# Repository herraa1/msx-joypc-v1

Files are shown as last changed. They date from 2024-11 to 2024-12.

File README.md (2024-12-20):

# PC gameport joystick controller adapter for MSX (msx-joypc) v1

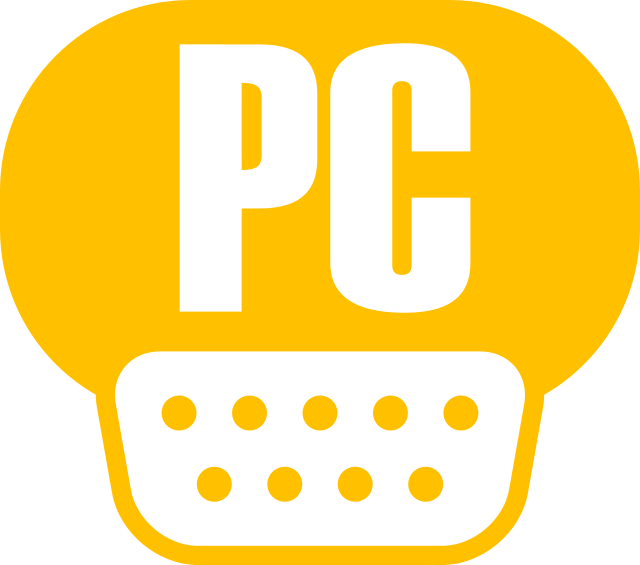
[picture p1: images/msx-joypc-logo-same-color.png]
[](images/msx-joypc-logo-same-color.png)

Connect [PC gameport joysticks](https://en.wikipedia.org/wiki/Game_port) to [MSX computers](https://www.msx.org/wiki/).

> [!NOTE]
>
> No build instructions are yet provided, but if you are brave enough go for the [recommended build](#recommended-build).
>

## Introduction

The msx-joypc v1 is an adapter that allows connecting PC gameport joysticks to [MSX general purpose I/O ports](https://www.msx.org/wiki/General_Purpose_port).

The main features of the msx-joypc v1 adapter are:
* small footprint
* made of widely available electronic components
* behaves as a cord extension between the MSX computer and the PC gameport joystick
* uses a female standard DE9 connector on the adapter's MSX joystick side
* uses a [DA-15](https://en.wikipedia.org/wiki/D-subminiature) socket on the adapter's PC gameport joystick side
* no need for external power supply, the adapter draws current from the MSX port
* low power consumption (<20mA)
* serial debug provides information about the operation of the adapter

## [Hardware](hardware/kicad/)

The msx-joypc v1 adapter uses an [Atmega328p](https://en.wikipedia.org/wiki/ATmega328) to convert the [PC gameport joystick signalling](https://www.epanorama.net/documents/joystick/pc_joystick.html) to the [MSX joystick standard signalling](https://www.msx.org/wiki/Joystick_control).

A two-sided printed circuit board (PCB) is used to put together all components:
* An Atmega328p as the main MCU, running at 5V 16MHz
* Two 74LS03 quad 2-input NAND gates with open collectors to completely mimic the standard MSX joystick behavior
* A PTC fuse to minimize damage to the MSX computer in case something goes wrong with the board
* Several additional required components (crystal, diode, leds, resistors, ceramic capacitors and a tantalum capacitor)
* An angled DA-15 socket is used to directly connect the PC gameport joystick
* A PH2.0 connector is used to connect the MSX cable extension
* A 2.54 pitch debug header is added for serial debug and programming
* An ICSP header is provided for burning a bootloader or to flash the chip using a hardware programmer
* A DIP switch to configure the adapter for compatibility with different PC joysticks

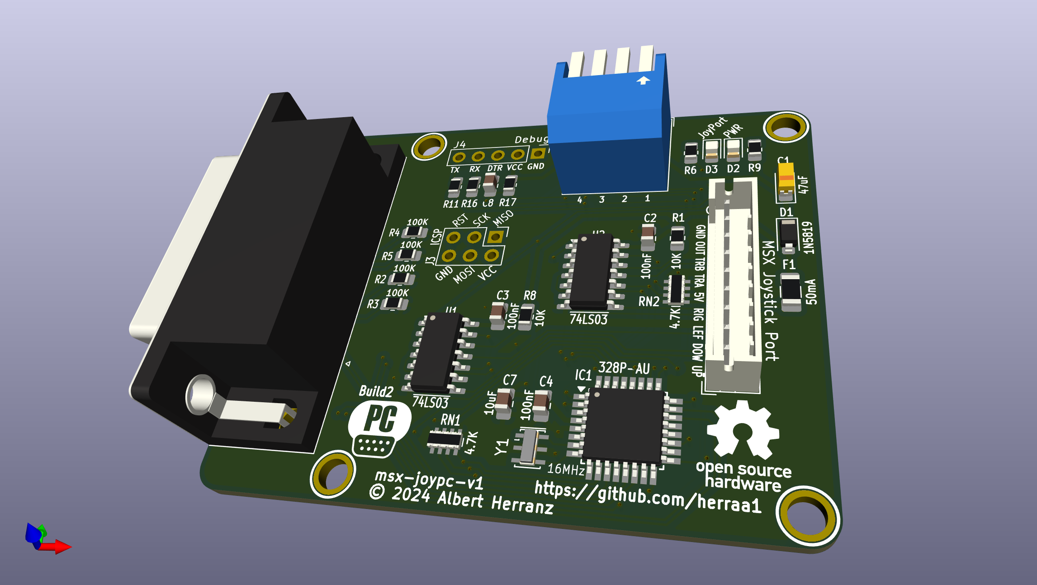
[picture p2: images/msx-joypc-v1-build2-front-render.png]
[](images/msx-joypc-v1-build2-front-render.png)
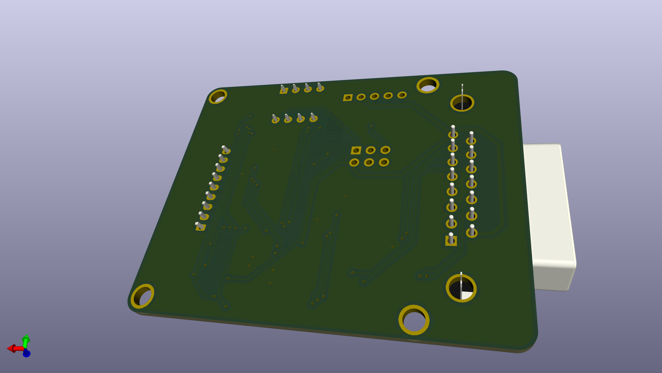
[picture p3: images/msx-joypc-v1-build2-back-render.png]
[](images/msx-joypc-v1-build2-back-render.png)

Connection to the MSX general purpose I/O port is implemented using a DE9 joystick extension cable with a female DE9 connector on one side and a loose end on the other side.
The MSX joystick extension cable loose end is wired according to the following pinout mapping.

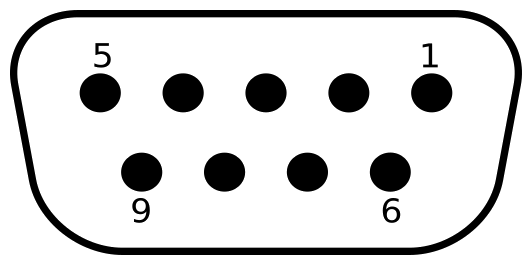
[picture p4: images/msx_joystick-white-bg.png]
| [](images/msx_joystick-white-bg.png) |
|:--|
| MSX joystick connector pinout, from controller plug side |

| MSX side pin | Cable color (may vary) | Signal |
| --- | --- | --- |
| 5 | Brown | +5v |
| 4 | Orange | RIGHT  |
| 3 | Grey | LEFT |
| 2 | Black | DOWN |
| 1 | Red | UP |
| 6 | Green | TRIGA  |
| 7 | White | TRIGB  |
| 8 | Blue | OUT |
| 9 | Yellow | GND |

The msx-joypc v1 is fully compatible with MSX joysticks and honors the pin8 (OUT) signal.

The adapter uses open collector outputs (using 74LS03 Quad 2-Input NAND gates with open collector outputs) which makes the adapter safer [^2] than the
standard MSX joystick schematic depicted in the MSX Technical Data Book, as it avoids a series of undesired conditions that can lead to bus contention/short circuits.

Power is drawn from the +5V signal of the MSX general purpose I/O port, which is capable of delivering up to 50mA [^1].
The msx-joypc v1 draws below 20mA from the port when a controller is connected, so it is on the safe side. Anyway, the msx-joypc adapter uses a Positive Temperature Coeficient (PTC) resettable fuse of 50mA (F1) to limit current in case something goes wrong.

Also on the power side, a [1N5819 Schottky diode](https://www.diodes.com/assets/Datasheets/1N5819HW.pdf) (D1) is used to avoid leaking current from the msx-joypc adapter to the MSX in case power is applied to one of the VCC pins available on the ICSP or Debug headers while the adapter is plugged into an MSX.

Connection to the PC gameport joystick is done via a PC gameport joystick socket.

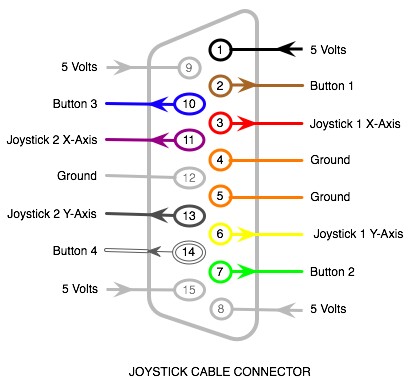
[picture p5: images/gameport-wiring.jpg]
| [](images/gameport-wiring.jpg) |
|:--|
| Gameport connector pinout, from PC gameport joystick side |

| Gameport pin | Signal | Comment |
| --- | ---| --- |
| 1 | +5V | +5V power |
| 2 | B1 | Button1 |
| 3 | X1 | Joystick 1 - X axis |
| 4 | GND | ground |
| 5 | GND | ground |
| 6 | Y1 | Joystick 1 - Y axis |
| 7 | B2 | Button2 |
| 8 | +5V | +5V power |
| 9 | +5V | +5V power |
| 10 | B3 | Button3 |
| 11 | X2 | Joystick 2 - X axis |
| 12 | GND/MIDI_OUT | ground / MIDI out |
| 13 | Y2 | Joystick 2 - Y axis |
| 14 | B4 | Button4 |
| 15 | +5V/MIDI_IN  | +5V power / MIDI_IN |

The PC gameport joystick uses 5V for power and logic.

Power for the PC gameport joystick is provided by the MSX +5V rail.

### Recommended Build

Please, use [msx-joypc-v1 Build2](#build2) for making new boards.

### [Build2](hardware/kicad/msx-joypc-v1-build2)

[Bill Of Materials (BoM)](https://html-preview.github.io/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)

This build fixes the following errata:
- make the ICSP header work again
- add (optional) RN1 and RN2 4k7 pull-downs to joystick signals to avoid spurious button joystick actions while powering up

This board has been successfully built and works fine.

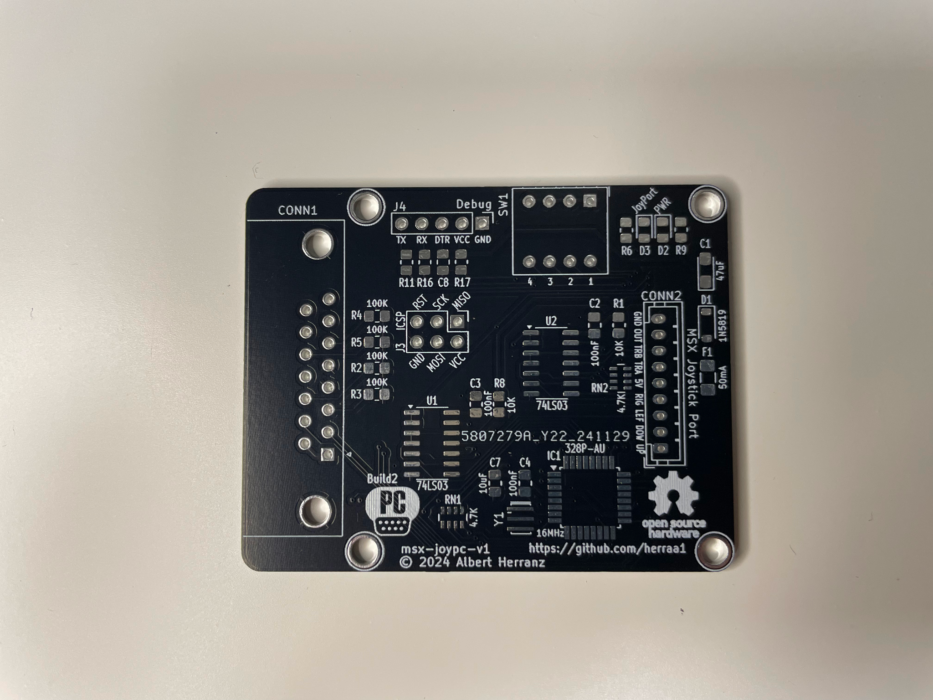
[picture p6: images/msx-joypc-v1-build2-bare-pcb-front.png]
[](images/msx-joypc-v1-build2-bare-pcb-front.png)
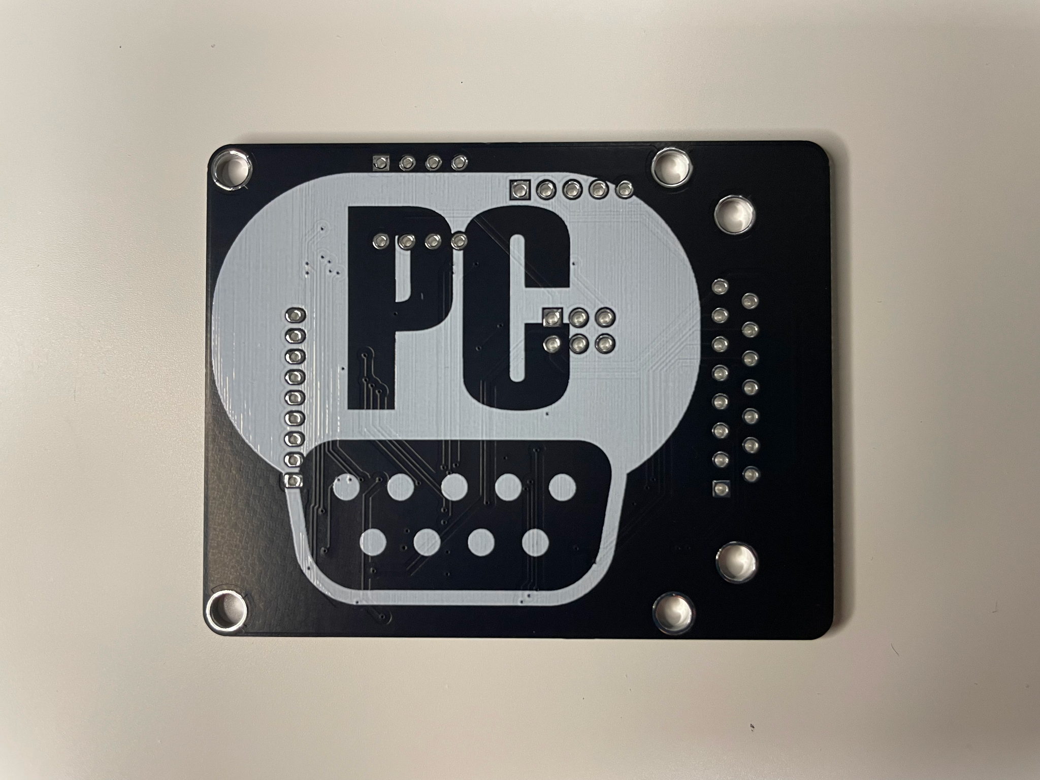
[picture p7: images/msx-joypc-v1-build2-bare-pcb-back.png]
[](images/msx-joypc-v1-build2-bare-pcb-back.png)

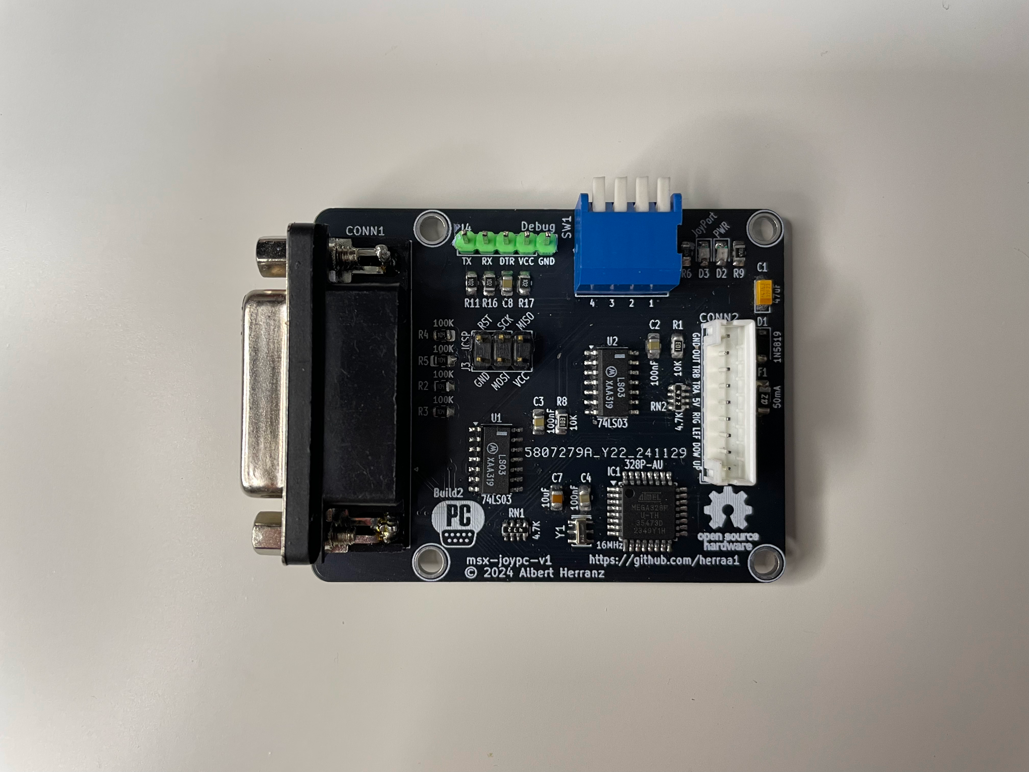
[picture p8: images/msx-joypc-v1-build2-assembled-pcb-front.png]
[](images/msx-joypc-v1-build2-assembled-pcb-front.png)
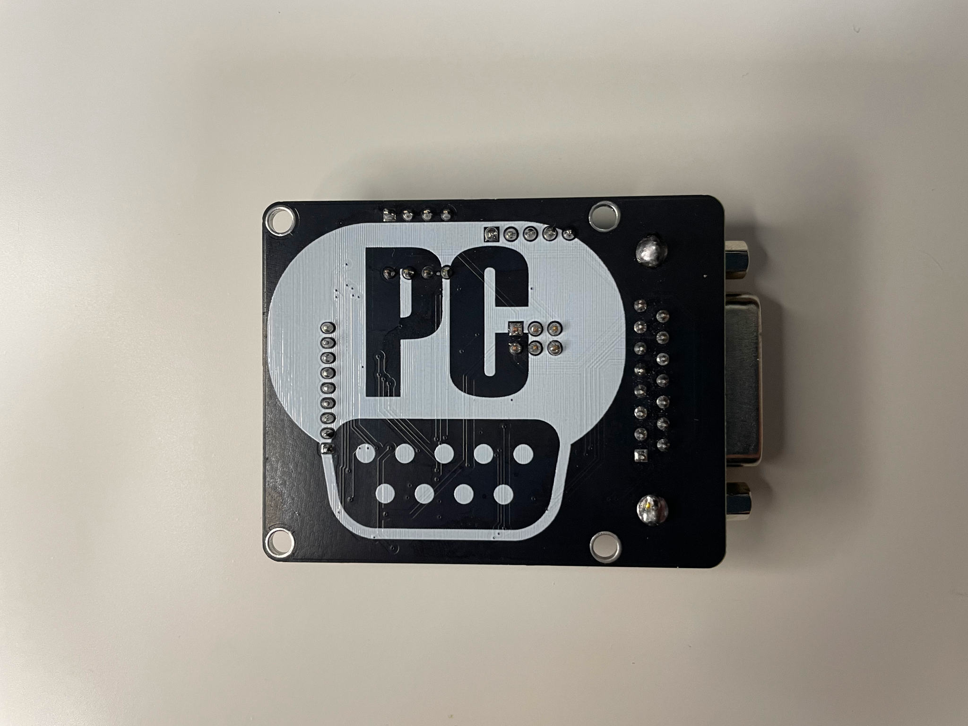
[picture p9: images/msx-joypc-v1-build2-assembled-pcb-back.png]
[](images/msx-joypc-v1-build2-assembled-pcb-back.png)

### Build1

> [!WARNING]
> This build is broken. I messed up the ICSP header after a last-minute pin reordering. Meh.
> It can be fixed by cutting two traces, exposing two traces and using a pair of jumper wires to bridge the necessary points.
>
> Do NOT build. Use the [recommended build](#recommended-build) instead.
>

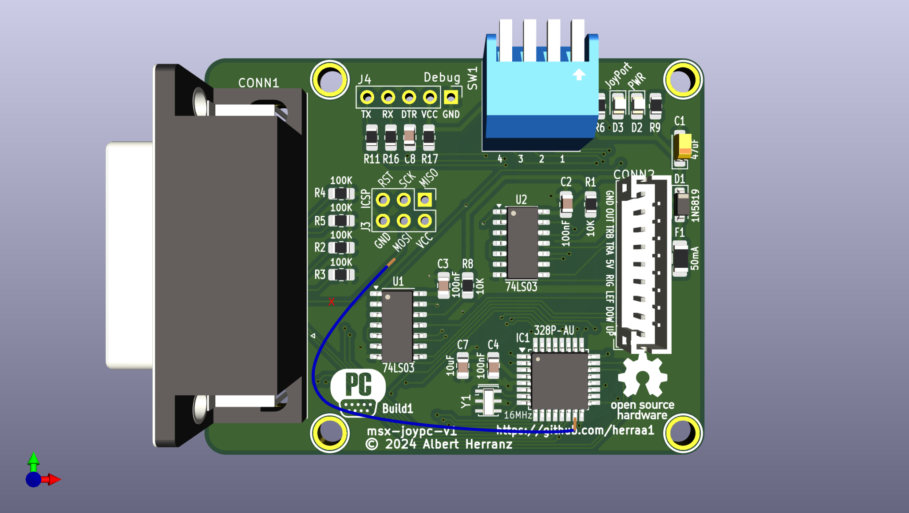
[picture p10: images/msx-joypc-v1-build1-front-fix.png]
[](images/msx-joypc-v1-build1-front-fix.png)
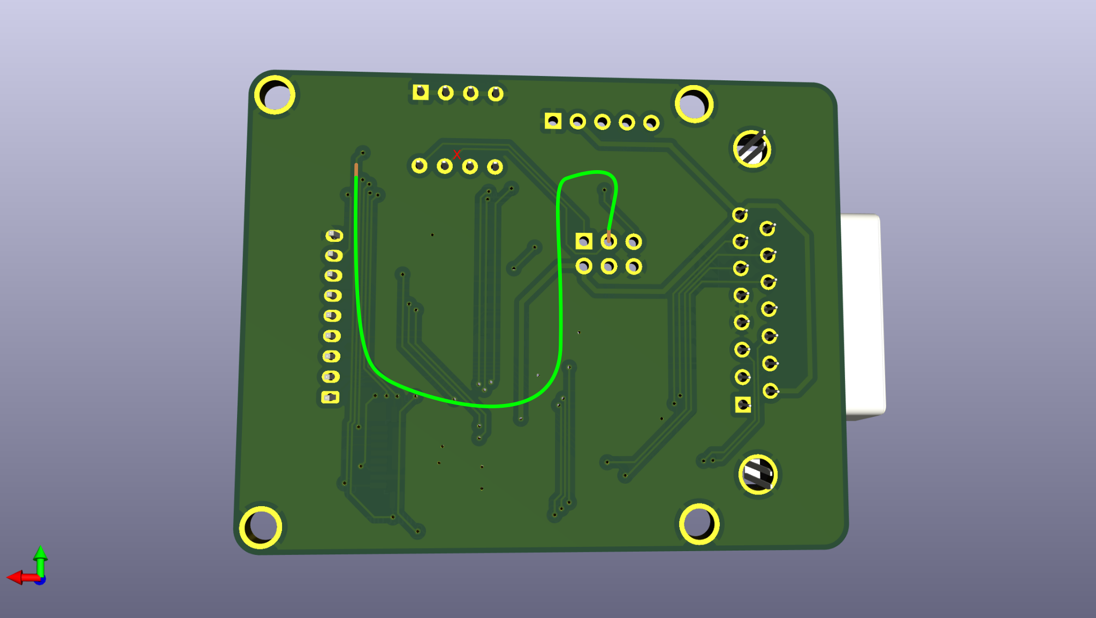
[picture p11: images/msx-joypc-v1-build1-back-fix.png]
[](images/msx-joypc-v1-build1-back-fix.png)

## [Firmware](firmware/msx-joypc-v1/)

The msx-joypc v1 adapter firmware uses a slightly modified version of [Necroware's GamePort adapter firmware](https://github.com/necroware/gameport-adapter) to read the PC gameport joystick status.

The following elements are used as inputs:
* joystick X and Y axis as direction arrows
* button 1, as Trigger 1
* button 2, as Trigger 2

Those elements' status are processed by the msx-joypc firmware and transformed into MSX general purpose I/O port's signals on the fly.

## [Enclosure](enclosure/)

### Acrylic

A simple acrylic enclosure design for the project is provided to protect the electronic components and provide strain relief for the extension cord.

The enclosure uses a 3mm acrylic sheet.

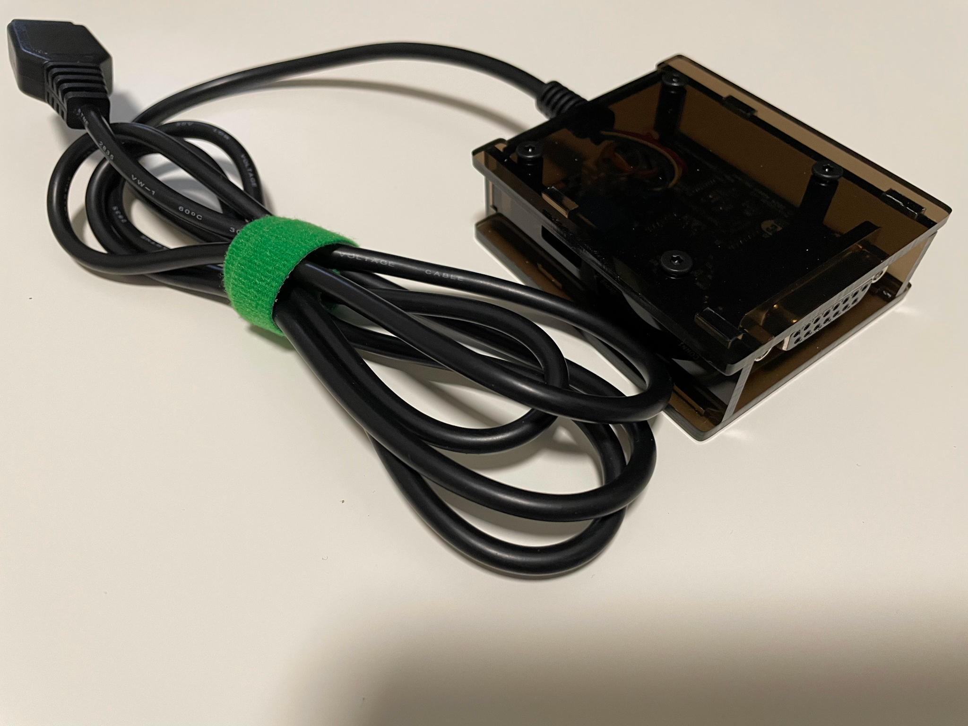
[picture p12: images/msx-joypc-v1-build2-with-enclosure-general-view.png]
[](images/msx-joypc-v1-build2-with-enclosure-general-view.png)

## Configuration Switches

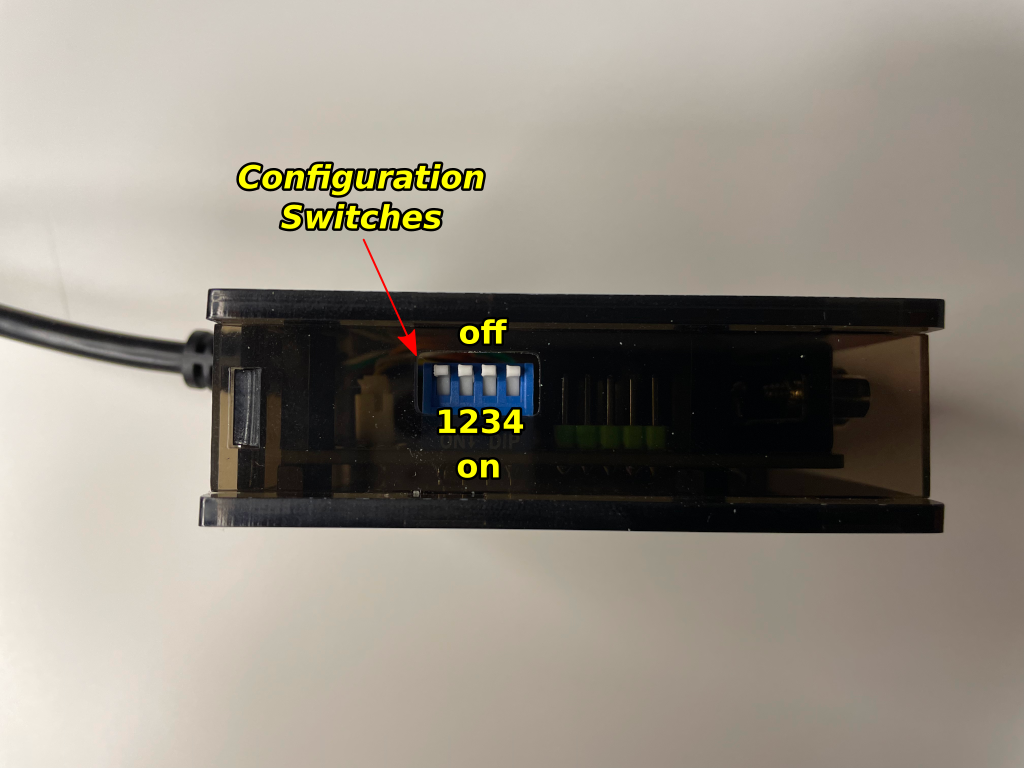
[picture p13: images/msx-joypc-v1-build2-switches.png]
[](images/msx-joypc-v1-build2-switches.png)

Joystick Model               | Buttons | Axes  |  Hat | SW1-4 | Protocol   | Comments
-----------------------------|---------|-------|------|-------|------------|------------------------------------
Generic Analog               | 2       | 2     | 0    | 0000  | Analogue   |
Generic Analog               | 4       | 2     | 0    | 1000  | Analogue   |
Generic Analog               | 4       | 3     | 0    | 0100  | Analogue   | 3rd Axis is throttle
Generic Analog               | 4       | 4     | 0    | 1100  | Analogue   |
CH FlightStick               | 4       | 4     | 1    | 0010  | Analogue   |
CH F16 Combat Stick          | 10      | 3     | 1    | 0110  | Analogue   |
ThrustMaster                 | 4       | 3     | 1    | 1010  | Analogue   |
Sidewinder GamePad           | 10      | 2     | 0    | 1110  | Sidewinder |
Sidewinder 3D Pro            | 8       | 4     | 1    | 1110  | Sidewinder |
Sidewinder 3D Pro Plus       | 9       | 4     | 1    | 1110  | Sidewinder | First version of Precision Pro
Sidewinder Precision Pro     | 9       | 4     | 1    | 1110  | Sidewinder |
Sidewinder FFB Pro           | 9       | 4     | 1    | 1110  | Sidewinder | FFB not yet implemented
Sidewinder FFB Wheel         | 8       | 3     | 0    | 1110  | Sidewinder | FFB not yet implemented
Gravis GamePad Pro           | 10      | 2     | 0    | 0001  | GrIP       |
Logitech WingMan Extreme     | 6       | 3     | 1    | 1001  | ADI        |
Logitech CyberMan 2          | 8       | 6     | 0    | 1001  | ADI        |
Logitech WingMan Interceptor | 9       | 3     | 3    | 1001  | ADI        | 2 hats are mapped as 4 axes
Logitech ThunderPad Digital  | 8       | 2     | 0    | 1001  | ADI        | Directional buttons mapped as 2 axes
Logitech WingMan Gamepad     | 11      | 2     | 0    | 1001  | ADI        | Directional buttons mapped as 2 axes
Logitech WingMan Light       | 2       | 2     | 0    | 0000  | Analogue   |

For an up to date information see [Which joysticks does this adapter support](https://github.com/necroware/gameport-adapter?tab=readme-ov-file#which-joysticks-does-this-adapter-support) on [Necroware's GamePort adapter project](https://github.com/necroware/gameport-adapter).

## LED indicators

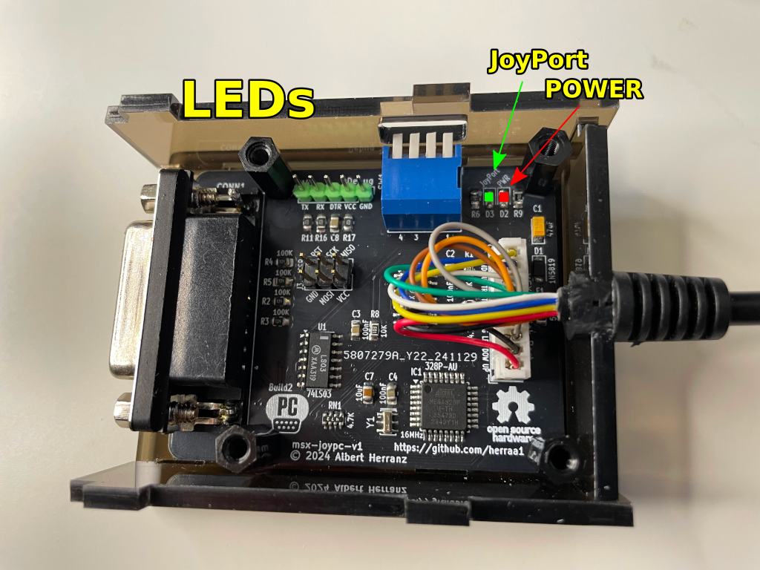
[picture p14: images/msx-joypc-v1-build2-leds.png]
[](images/msx-joypc-v1-build2-leds.png)

| **LED** | **State** | **Indication** |
|---|---|---|
| _POWER_ | Off | board is not receiving 5V power |
| _POWER_ | Solid Red | board is receiving 5V power |
| _JoyPort_ | Off | no PC joystick connected or recognized |
| _JoyPort_ | Solid Green | PC joystick connected and ready to use |

## References

MSX general purpose I/O port
* https://www.msx.org/wiki/General_Purpose_port

Atmega328p pinout
- https://camo.githubusercontent.com/06bc0a6bb71729956af107f56c3e57bd065d9fb924bcc7f6bb8fbb487a1a5e55/68747470733a2f2f692e696d6775722e636f6d2f6e6177657145362e6a7067

Joystick PC Gameport pinout
* https://allpinouts.org/pinouts/connectors/input_device/joystick-pc-gameport/

PC joystick interface
* https://www.epanorama.net/documents/joystick/pc_joystick.html

Necroware's GamePort adapter project
* https://github.com/necroware/gameport-adapter

Using a PC Joystick with the Arduino
* http://www.built-to-spec.com/blog/2009/09/10/using-a-pc-joystick-with-the-arduino/

Arduino gameport interface
* https://build-its.blogspot.com/2012/01/arduino-game-port-interface.html

DIY gameport to USB adapter
* https://littlebigtech.net/posts/diy-gameport-to-usb-adapter/

## Image Sources

* https://www.oshwa.org/open-source-hardware-logo/
* https://en.wikipedia.org/wiki/File:Numbered_DE9_Diagram.svg

[^1]: https://www.msx.org/wiki/General_Purpose_port
[^2]: https://www.msx.org/wiki/Joystick/joypad_controller (see "Undesired Conditions")

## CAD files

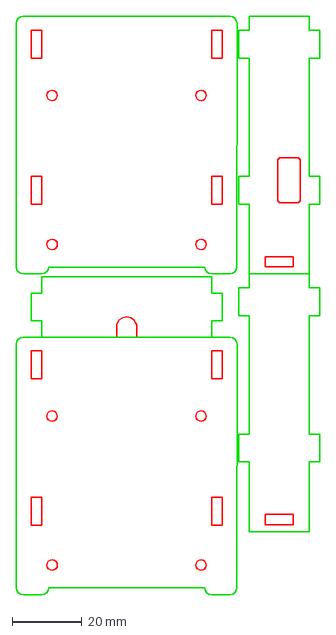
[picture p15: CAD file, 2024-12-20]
enclosure/msx-joypc-v1-case-acrylic-3mm-ready-to-lasercut.dxf
87.1 x 166.1 mm

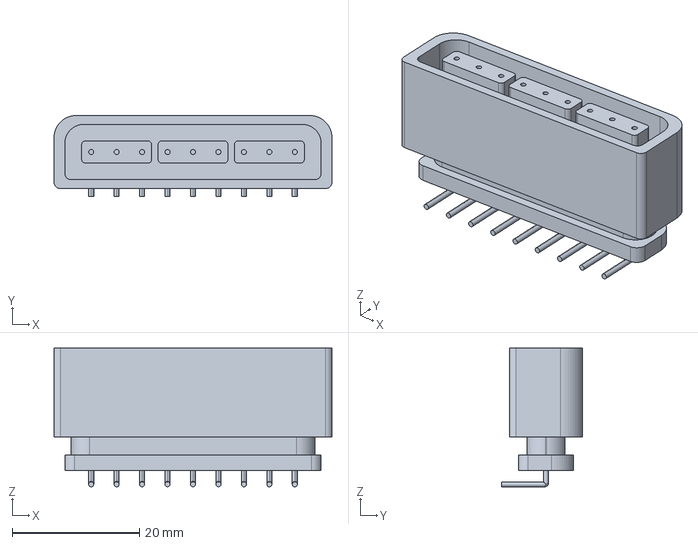
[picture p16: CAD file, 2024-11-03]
hardware/kicad/msx-joypc-v1-build2/compo/3dmodels/ps-connector-female/pritesh.stp
43.7 x 12.8 x 21.8 mm

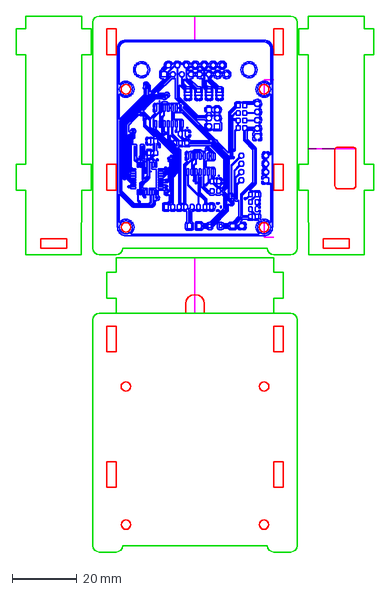
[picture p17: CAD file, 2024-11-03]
enclosure/msx-joypc-v1-case.dxf
110.9 x 166.1 mm

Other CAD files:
hardware/kicad/msx-joypc-v1-build2/compo/3dmodels/ps-connector-female/pritesh.igs

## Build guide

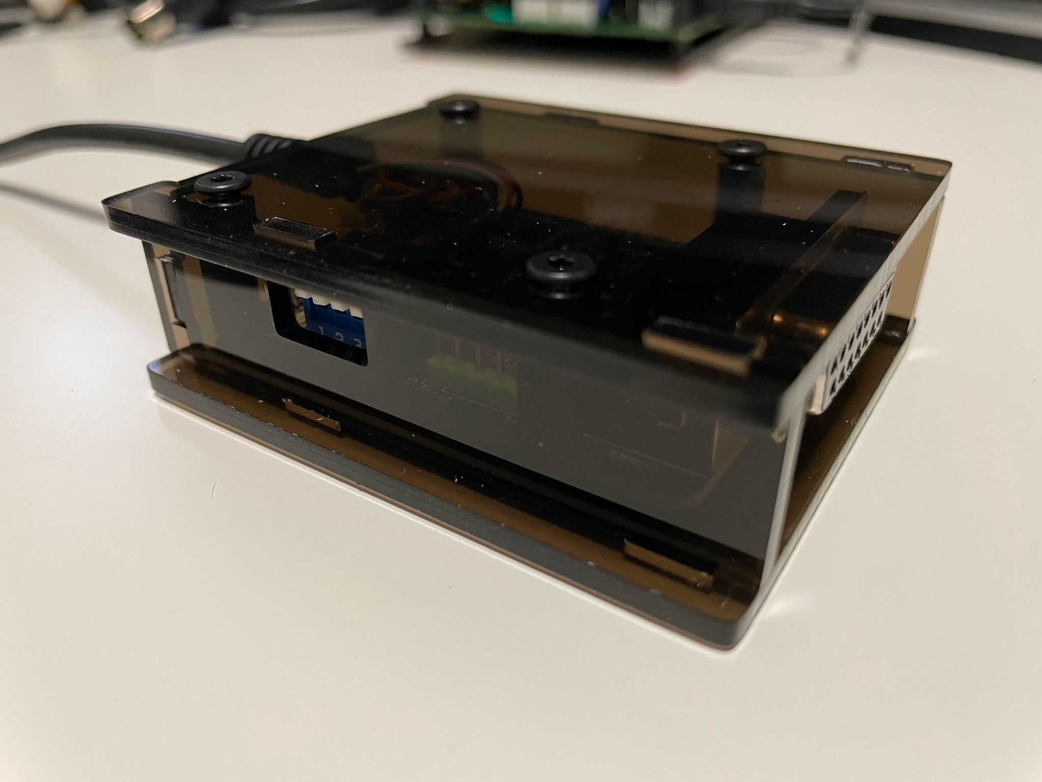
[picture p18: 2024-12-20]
images/msx-joypc-v1-build2-with-enclosure-view-of-switches.png

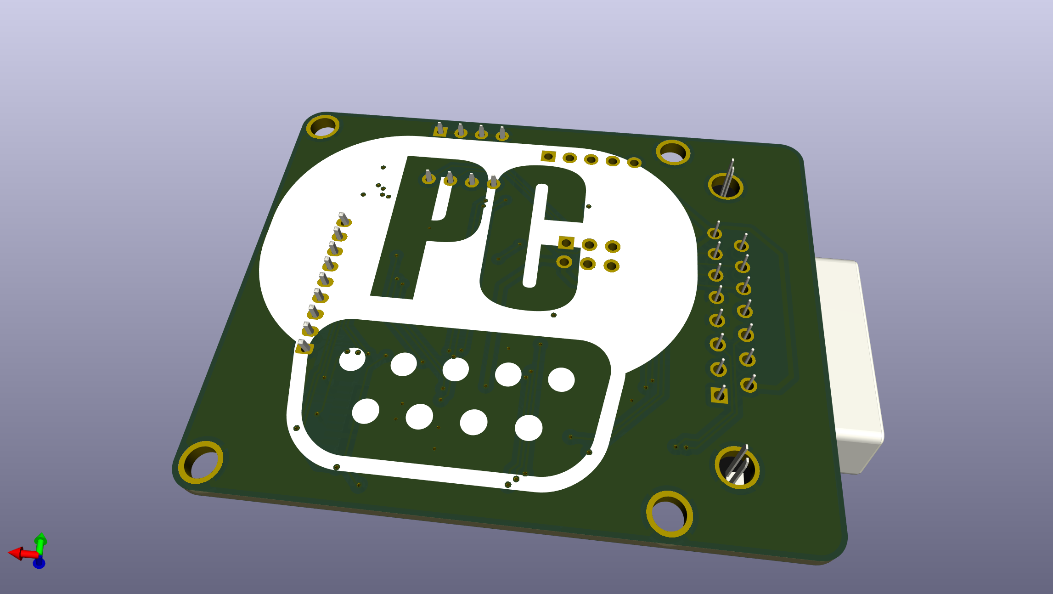
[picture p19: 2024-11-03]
images/msx-joypc-v1-build1-back-render.png

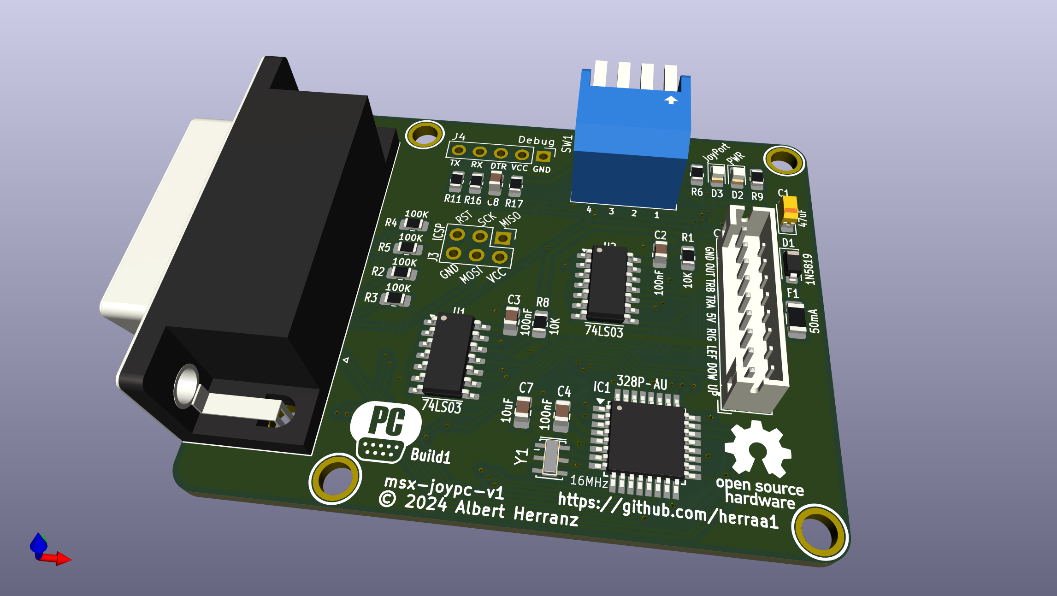
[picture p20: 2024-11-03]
images/msx-joypc-v1-build1-front-render.png

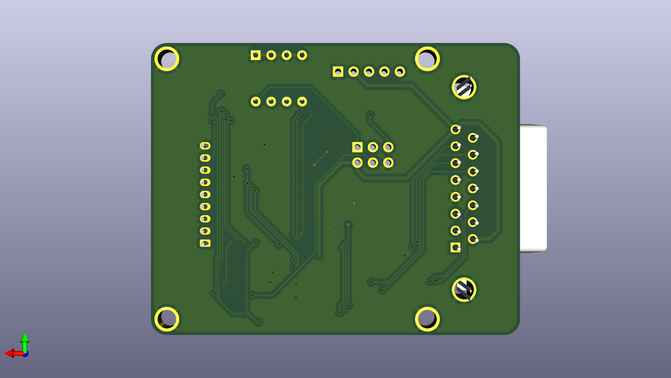
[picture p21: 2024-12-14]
images/msx-joypc-v1-build2-back.png

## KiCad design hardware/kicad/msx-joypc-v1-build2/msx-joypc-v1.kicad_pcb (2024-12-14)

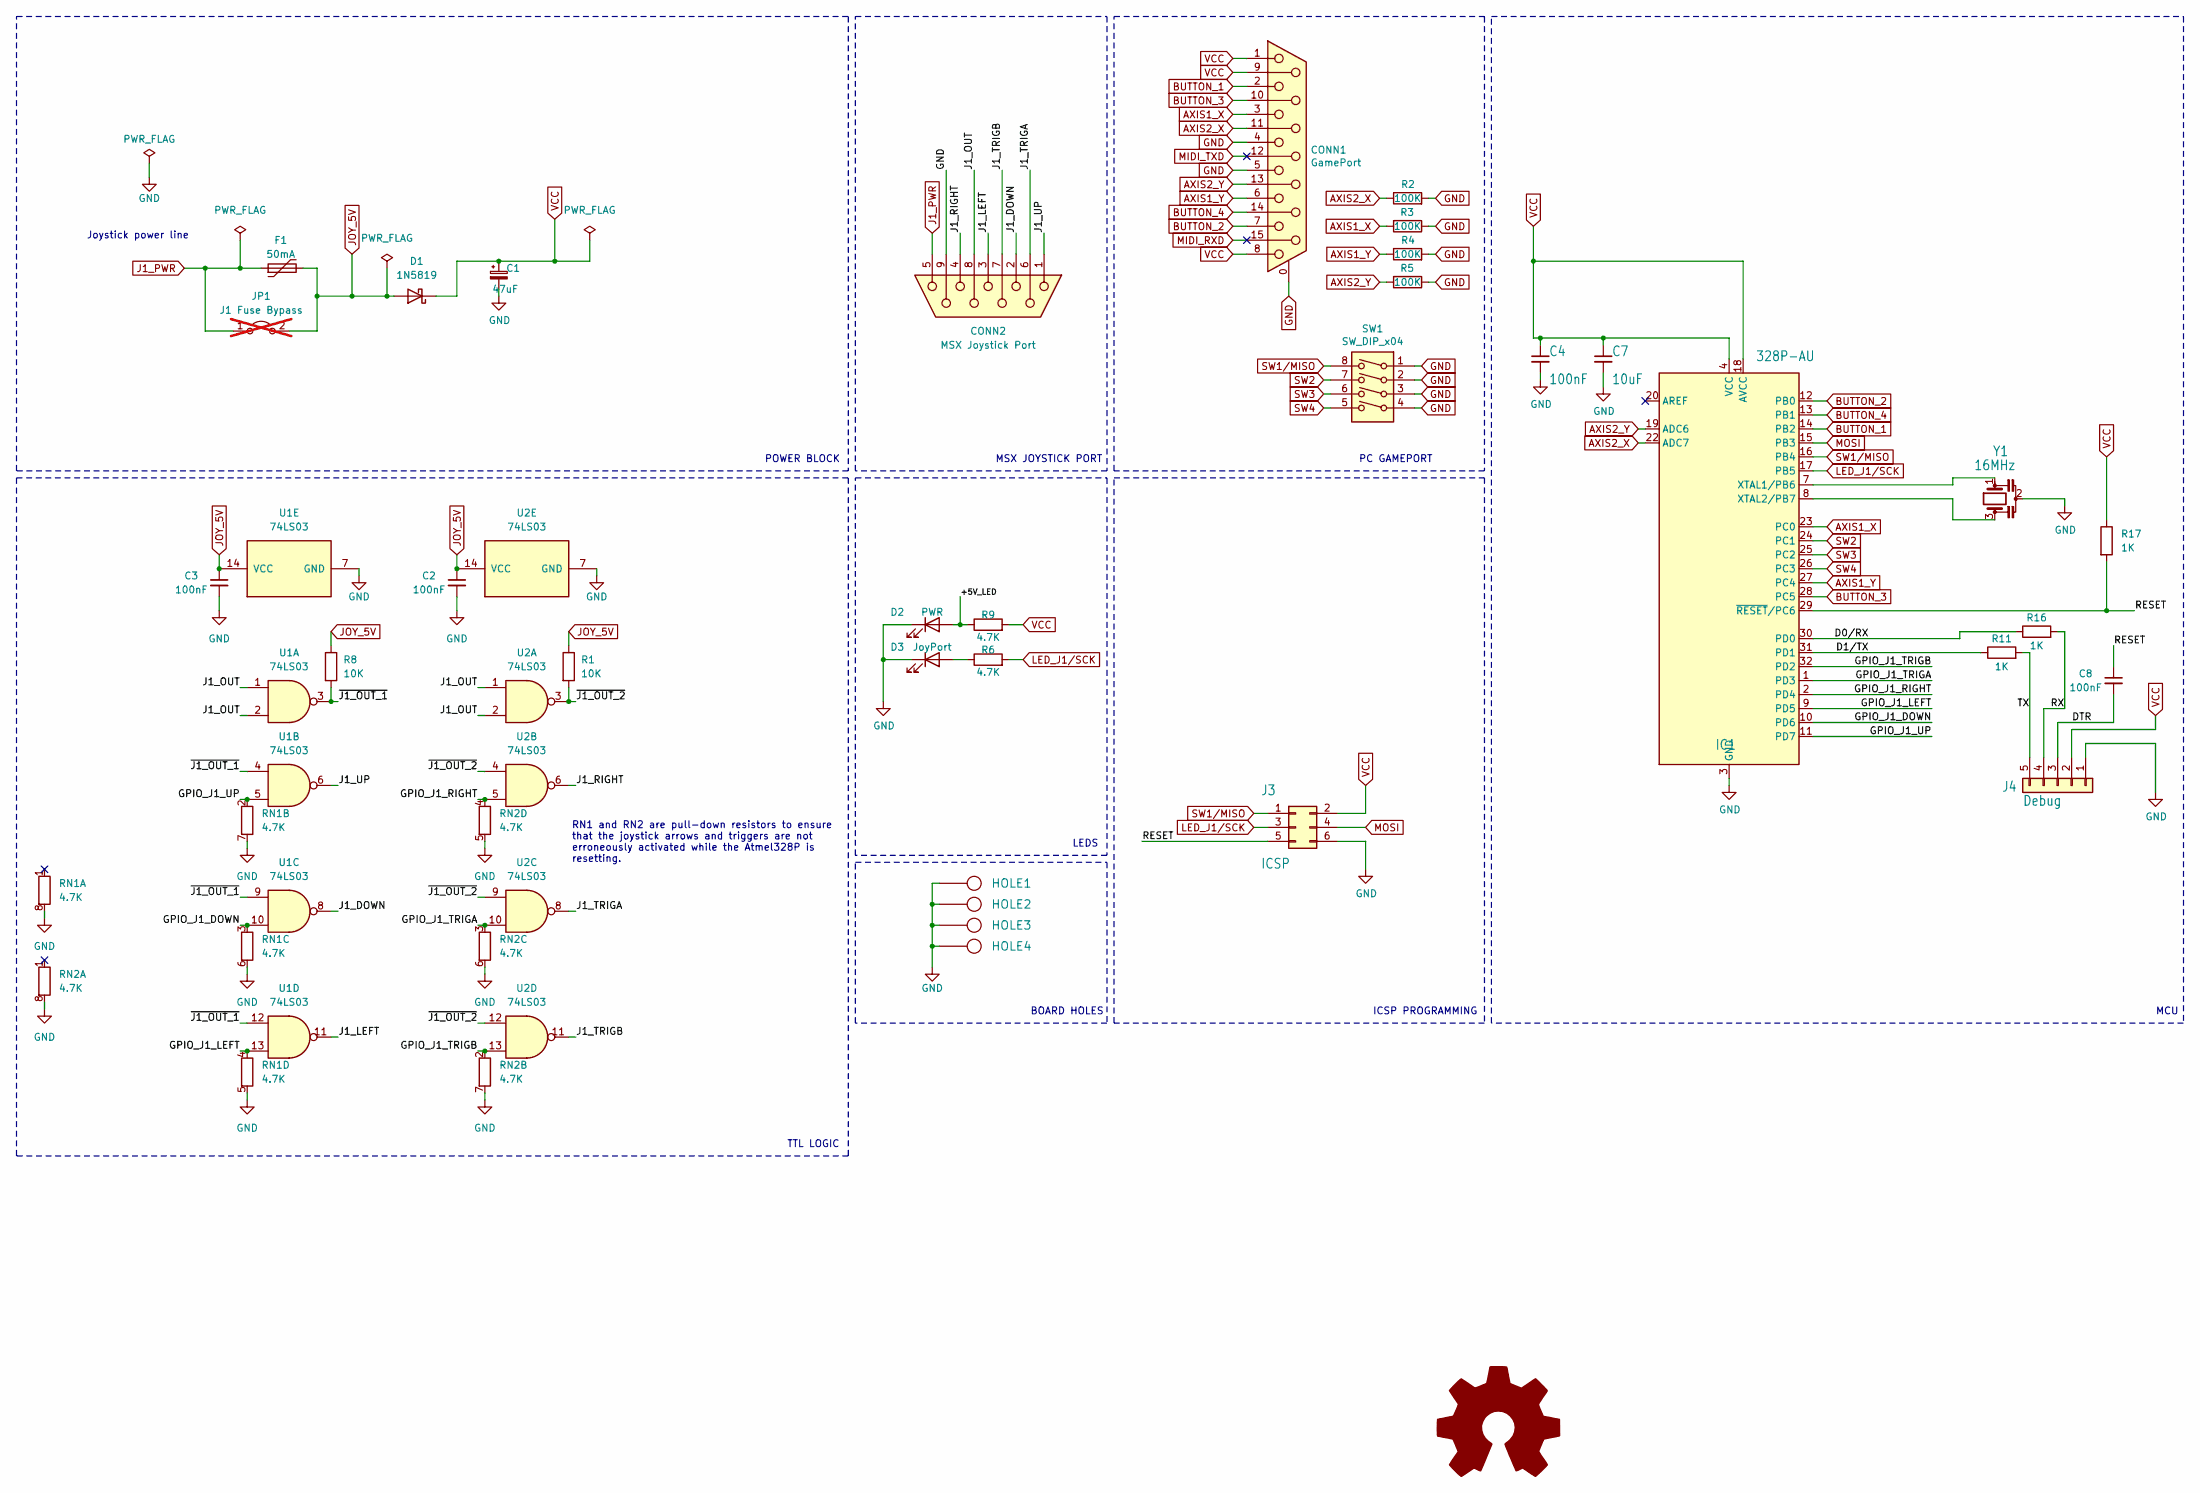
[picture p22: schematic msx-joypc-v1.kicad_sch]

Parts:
C1: 47uF; CP_EIA-3216-18_Kemet-A_Pad1.58x1.35mm_HandSolder
C2, C3, C4, C8: 100nF; C_0805_2012Metric_Pad1.18x1.45mm_HandSolder
C7: 10uF; C_0805_2012Metric_Pad1.18x1.45mm_HandSolder
CONN1: GamePort; DSUB-15_Female_Horizontal_P2.77x2.84mm_EdgePinOffset7.70mm_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; LCSC C77835
CONN2: MSX Joystick Port; JST_PH_B9B-PH-K_1x09_P2.00mm_Vertical
D1: 1N5819; D_SOD-123
D2: PWR; LED_0805_2012Metric_Pad1.15x1.40mm_HandSolder
D3: JoyPort; LED_0805_2012Metric_Pad1.15x1.40mm_HandSolder
F1: 50mA; Fuse_1206_3216Metric_Pad1.42x1.75mm_HandSolder
HOLE1, HOLE2, HOLE3, HOLE4: HOLE; Hole_3mm
IC1: 328P-AU; TQFP-32_7x7mm_P0.8mm
J3: ICSP; PinHeader_2x03_P2.54mm_Vertical
J4: Debug; PinHeader_1x05_P2.54mm_Vertical
JP1: J1 Fuse Bypass; PinHeader_1x02_P2.54mm_Vertical; not fitted
R1, R8: 10K; R_0805_2012Metric_Pad1.20x1.40mm_HandSolder
R2, R3, R4, R5: 100K; R_0805_2012Metric_Pad1.20x1.40mm_HandSolder; LCSC C172965
R6: 4.7K; R_0805_2012Metric_Pad1.20x1.40mm_HandSolder; LCSC C4310
R9: 4.7K; R_0805_2012Metric_Pad1.20x1.40mm_HandSolder
R11, R16, R17: 1K; R_0805_2012Metric_Pad1.20x1.40mm_HandSolder
RN1, RN2: 4.7K; R_Array_Concave_4x0603
SW1: SW_DIP_x04; SW_DIP_SPSTx04_Piano_10.8x11.72mm_W7.62mm_P2.54mm; LCSC C15781
SYM1: Logo_Open_Hardware_Large; OSHW-Logo_7.5x8mm_SilkScreen
U1, U2: 74LS03; SOIC-14_3.9x8.7mm_P1.27mm
Y1: 16MHz; Resonator_SMD_Murata_CSTxExxV-3Pin_3.0x1.1mm_HandSoldering

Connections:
/+5V_LED: D2.2 (A), R9.1
/D0/RX: IC1.30 (PD0), R16.1
/D1/TX: IC1.31 (PD1), R11.1
/DTR: C8.2, J4.3
/GPIO_J1_DOWN: IC1.10 (PD6), RN1.3 (R3.1), U1.10
/GPIO_J1_LEFT: IC1.9 (PD5), RN1.4 (R4.1), U1.13
/GPIO_J1_RIGHT: IC1.2 (PD4), RN2.4 (R4.1), U2.5
/GPIO_J1_TRIGA: IC1.1 (PD3), RN2.3 (R3.1), U2.10
/GPIO_J1_TRIGB: IC1.32 (PD2), RN2.2 (R2.1), U2.13
/GPIO_J1_UP: IC1.11 (PD7), RN1.2 (R2.1), U1.5
/J1_DOWN: CONN2.2, U1.8
/J1_LEFT: CONN2.3, U1.11
/J1_OUT: CONN2.8, U1.1, U1.2, U2.1, U2.2
/J1_RIGHT: CONN2.4, U2.6
/J1_TRIGA: CONN2.6, U2.8
/J1_TRIGB: CONN2.7, U2.11
/J1_UP: CONN2.1, U1.6
/RESET: C8.1, IC1.29 (~RESET/PC6), J3.5, R17.2
/RX: J4.4, R16.2
/TX: J4.5, R11.2
/~J1_OUT_1: R8.2, U1.3, U1.4, U1.9, U1.12
/~J1_OUT_2: R1.2, U2.3, U2.4, U2.9, U2.12
AXIS1_X: CONN1.3, IC1.23 (PC0), R3.2
AXIS1_Y: CONN1.6, IC1.27 (PC4), R4.1
AXIS2_X: CONN1.11 (P111), IC1.22 (ADC7), R2.1
AXIS2_Y: CONN1.13, IC1.19 (ADC6), R5.2
BUTTON_1: CONN1.2, IC1.14 (PB2)
BUTTON_2: CONN1.7, IC1.12 (PB0)
BUTTON_3: CONN1.10, IC1.28 (PC5)
BUTTON_4: CONN1.14, IC1.13 (PB1)
GND: C1.2, C2.2, C3.2, C4.2, C7.2, CONN1.0 (PAD), CONN1.4, CONN1.5, CONN2.9, D2.1 (K), D3.1 (K), HOLE1.1, HOLE2.1, HOLE3.1, HOLE4.1, IC1.3 (GND), IC1.5 (GND), IC1.21 (GND), J3.6, J4.1, R2.2, R3.1, R4.2, R5.1, RN1.5 (R4.2), RN1.6 (R3.2), RN1.7 (R2.2), RN1.8 (R1.2), RN2.5 (R4.2), RN2.6 (R3.2), RN2.7 (R2.2), RN2.8 (R1.2), SW1.1, SW1.2, SW1.3, SW1.4, U1.7 (GND), U2.7 (GND), Y1.2
J1_PWR: CONN2.5, F1.1, JP1.1 (A)
JOY_5V: C2.1, C3.1, D1.2 (A), F1.2, JP1.2 (B), R1.1, R8.1, U1.14 (VCC), U2.14 (VCC)
LED_J1/SCK: IC1.17 (PB5), J3.3, R6.2
MIDI_RXD: CONN1.15
MIDI_TXD: CONN1.12
MOSI: IC1.15 (PB3), J3.4
unnamed: D3.2 (A), R6.1
unnamed: IC1.7 (XTAL1/PB6), Y1.1
unnamed: IC1.8 (XTAL2/PB7), Y1.3
SW1/MISO: IC1.16 (PB4), J3.1, SW1.8
SW2: IC1.24 (PC1), SW1.7
SW3: IC1.25 (PC2), SW1.6
SW4: IC1.26 (PC3), SW1.5
VCC: C1.1, C4.1, C7.1, CONN1.1, CONN1.8, CONN1.9, D1.1 (K), IC1.4 (VCC), IC1.6 (VCC), IC1.18 (AVCC), J3.2, J4.2, R9.2, R17.1

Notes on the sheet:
MCU
LEDS
MSX JOYSTICK PORT
TTL LOGIC
BOARD HOLES
Joystick power line
ICSP PROGRAMMING
RN1 and RN2 are pull-down resistors to ensure that the joystick arrows and triggers are not erroneously activated while the Atmel328P is resetting.
PC GAMEPORT
POWER BLOCK

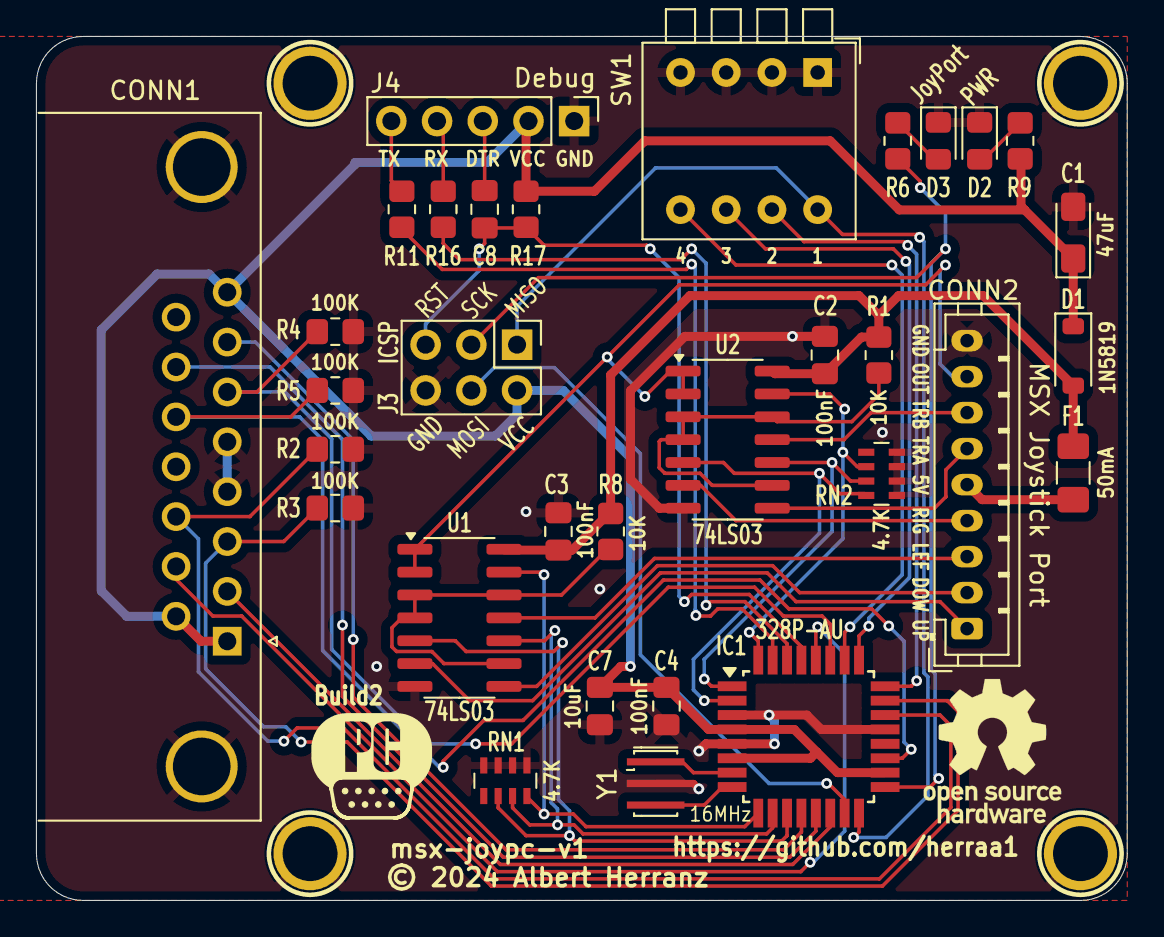
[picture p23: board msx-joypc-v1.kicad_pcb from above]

Board: 2 copper layers, 60.6 x 48.0 mm, 37 parts (0 on the bottom side), 43 nets.

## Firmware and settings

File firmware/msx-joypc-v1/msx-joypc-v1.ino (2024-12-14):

/*
 * msx-joypc v1, a PC gameport to MSX joystick adapter
 * Copyright (C) 2024 Albert Herranz
 *
 * This code is released under GPL V2.0
 *
 * Valid-License-Identifier: GPL-2.0-only
 * SPDX-URL: https://spdx.org/licenses/GPL-2.0-only.html
 *
 */
 /*

Built using Arduino 2.2.1
Boards:
- Minicore 2.2.2
  - Board: Atmega328
  - BOD 1.8V
  - Bootloader: Yes (UART0)
  - Clock: External 16MHz
  - EEPROM: Retained
  - Compiler LTO: Disabled
  - Variant: 328P/328PA

  */
//
// Based on Necroware's GamePort adapter firmware.
// Copyright (C) 2021 Necroware
//
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
#include "DigitalPin.h"
#include "MsxJoystick.h"

#include "CHFlightstickPro.h"
#include "CHF16CombatStick.h"
#include "GenericJoystick.h"
#include "GrIP.h"
#include "Logitech.h"
#include "Sidewinder.h"
#include "ThrustMaster.h"

#include <avr/wdt.h>

static Joystick *createJoystick() {

  const auto sw1 = DigitalInput<12, true>{};
  const auto sw2 = DigitalInput<A1, true>{};
  const auto sw3 = DigitalInput<A2, true>{};
  const auto sw4 = DigitalInput<A3, true>{};

  // Give some time to setup the input
  delay(1);

  const auto sw = !sw4 << 3 | !sw3 << 2 | !sw2 << 1 | !sw1;
  log("Configuration switches = 0x%0x", sw);

  switch (sw) {
    case 0b0001:
      return new GenericJoystick<2,4>;
    case 0b0010:
      return new GenericJoystick<3,4>;
    case 0b0011:
      return new GenericJoystick<4,4>;
    case 0b0100:
      return new CHFlightstickPro;
    case 0b0101:
      return new ThrustMaster;
    case 0b0110:
      return new CHF16CombatStick;
    case 0b0111:
      return new Sidewinder;
    case 0b1000:
      return new GrIP;
    case 0b1001:
      return new Logitech;
    default:
      return new GenericJoystick<2,2>;
  }
}

void setup() {
    MCUSR = 0;
    wdt_disable();

    // DEBUG information: Debugging is turned off by default
    // Comment the "NDEBUG" line in "Utilities.h" to enable logging to the serial monitor
    initLog();
    log("msx-joypc-v1 20241110_1");
}

void loop() {
    static auto msxJoystick = [] {
        MsxJoystick msxJoystick;
        msxJoystick.init(createJoystick());
        return msxJoystick;
    }();

    msxJoystick.update();
    delay(2);
}

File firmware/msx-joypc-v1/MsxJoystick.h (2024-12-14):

/*
 * msx-joypc v1, a PC gameport to MSX joystick adapter
 * Copyright (C) 2024 Albert Herranz
 *
 * This code is released under GPL V2.0
 *
 * Valid-License-Identifier: GPL-2.0-only
 * SPDX-URL: https://spdx.org/licenses/GPL-2.0-only.html
 *
 */
//
// Based on Necroware's GamePort adapter firmware.
// Copyright (C) 2021 Necroware
//
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
#pragma once

#include "Buffer.h"
#include "Joystick.h"
#include "Utilities.h"
#include <Arduino.h>

#include "DigitalPin.h"
#include <avr/wdt.h>

void __force_system_reset(void) {
	MCUSR = 0;
	wdt_enable(WDTO_250MS);
	while(1)  ;  // force WDT to reset system
}

class MsxJoystick {
public:
  bool init(Joystick *joystick) {
    
    if (!joystick || !joystick->init()) {
      return false;
    }

    m_joystick = joystick;
    m_state = State::BOOT_CONNECTED_CONNECTED;
    m_led.setHigh();

    const auto &desc = m_joystick->getDescription();
    log("Configured device: %s (%d axes, %d buttons)", desc.name, desc.numAxes, desc.numButtons);

    return true;
  }

  bool update() {
    if (!m_joystick || !m_joystick->update()) {
      return false;
    }

    const auto &state = m_joystick->getState();
    const auto &desc = m_joystick->getDescription();

#ifdef DIAG
    static auto last_state = m_joystick->getState();

    for (auto i = 0u; i < desc.numAxes; i++) {
        log_nolf("axes[%d] = %d,", i, state.axes[i]);
    }

    if (desc.hasHat) {
      if (last_state.hat != state.hat) {
        log_nolf("hat = %d,", state.hat);
      }
    }

    if (desc.numButtons) {
      if (last_state.buttons != state.buttons) {
        log_nolf("buttons = %d", state.buttons);
      }
    }
    log_nolf("\n");

    last_state = state;
#endif

    int16_t lx, ly;

    ly = (1 < desc.numAxes)?state.axes[1]:s_axis_threshold_min;
    lx = (0 < desc.numAxes)?state.axes[0]:s_axis_threshold_min;

    if (lx == 1023 && ly == 1023) {
        switch(m_state) {
            case State::BOOT_CONNECTED_CONNECTED:
                m_state = State::BOOT_CONNECTED_UNCONNECTED_MAYBE;
                m_last_state_millis = millis();
                break;
            case State::BOOT_CONNECTED_UNCONNECTED_MAYBE:
                unsigned long current_millis = millis();
                if (current_millis - m_last_state_millis >= s_joystick_dead_time) {
                    // adapter started with joystick connected, but joystick was disconnected
                    m_state = State::BOOT_CONNECTED_UNCONNECTED_CONFIRMED;
                    m_last_state_millis = millis();
                    log("Adapter booted with joystick connected, but now joystick is disconnected");
                    m_led.setLow();
                }
                break;
        }
    } else if (lx == 511 && ly == 511) {
        switch(m_state) {
            case State::BOOT_CONNECTED_CONNECTED:
                m_state = State::BOOT_UNCONNECTED_UNCONNECTED_MAYBE;
                m_last_state_millis = millis();
                break;
            case State::BOOT_UNCONNECTED_UNCONNECTED_MAYBE:
                unsigned long current_millis = millis();
                if (current_millis - m_last_state_millis >= s_joystick_dead_time) {
                    // adapter started with joystick not connected, joystick still disconnected
                    m_state = State::BOOT_UNCONNECTED_UNCONNECTED_CONFIRMED;
                    m_last_state_millis = millis();
                    log("Adapter booted with joystick disconnected");
                    m_led.setLow();
                    __update_msx_signals(0);
                }
                break;
        }
    } else {
        switch(m_state) {
            case State::BOOT_CONNECTED_UNCONNECTED_CONFIRMED:
                // fallthrough
            case State::BOOT_UNCONNECTED_UNCONNECTED_CONFIRMED:
                log("Joystick reconnected, restarting adapter!");
                delay(5);
                __force_system_reset();
                break;
        }
        m_state = State::BOOT_CONNECTED_CONNECTED;
    }

    uint8_t joystick_signals = 0x00;

    if (m_state != State::BOOT_CONNECTED_UNCONNECTED_CONFIRMED && m_state != State::BOOT_UNCONNECTED_UNCONNECTED_CONFIRMED) {
        if ((state.buttons & 0x01) || (state.buttons & 0x04))
            joystick_signals |= (1 << MsxPortPins::MSX_JOYSTICK_TRIGGER1);

        if ((state.buttons & 0x02) || (state.buttons & 0x08))
            joystick_signals |= (1 << MsxPortPins::MSX_JOYSTICK_TRIGGER2);

        if ((ly > s_axis_threshold_max) && !(joystick_signals & (1 << MsxPortPins::MSX_JOYSTICK_UP)))
            joystick_signals |= (1 << MsxPortPins::MSX_JOYSTICK_DOWN);

        /* before activating UP check that DOWN is not activated */
        if ((ly < s_axis_threshold_min) && !(joystick_signals & (1 << MsxPortPins::MSX_JOYSTICK_DOWN)))
            joystick_signals |= (1 << MsxPortPins::MSX_JOYSTICK_UP);

        /* before activating LEFT check that RIGHT is not activated */
        if ((lx < s_axis_threshold_min) && !(joystick_signals & (1 << MsxPortPins::MSX_JOYSTICK_RIGHT)))
            joystick_signals |= (1 << MsxPortPins::MSX_JOYSTICK_LEFT);

        /* before activating RIGHT check that LEFT is not activated */
        if ((lx > s_axis_threshold_max) && !(joystick_signals & (1 << MsxPortPins::MSX_JOYSTICK_LEFT)))
            joystick_signals |= (1 << MsxPortPins::MSX_JOYSTICK_RIGHT);
    }

    __update_msx_signals(joystick_signals);

    return true;
  }

private:
  static constexpr unsigned long s_joystick_dead_time = 2UL * 1000UL; // 2 seconds
  static constexpr auto s_axis_threshold = (1023 - 0) / 3;
  static constexpr auto s_axis_threshold_min = 0 + s_axis_threshold;
  static constexpr auto s_axis_threshold_max = 1023 - s_axis_threshold;

  Joystick *m_joystick{};
  DigitalOutput<13> m_led;

  enum class State {
    BOOT_CONNECTED_CONNECTED,
    BOOT_CONNECTED_UNCONNECTED_MAYBE,
    BOOT_CONNECTED_UNCONNECTED_CONFIRMED,
    BOOT_UNCONNECTED_UNCONNECTED_MAYBE,
    BOOT_UNCONNECTED_UNCONNECTED_CONFIRMED
  };

  unsigned long m_last_state_millis;
  State m_state;
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

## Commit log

2024-11-03 Initial commit.
    [msx-joypc-v1-case.dxf, msx-joypc-v1.kicad_pcb, msx-joypc-v1.kicad_sch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]
2024-11-09 firmware: fix reset loop when bootloader that does not disable the watchdog
    [msx-joypc-v1.ino]
2024-12-14 kicad: add build2
    [msx-joypc-v1.kicad_pcb, msx-joypc-v1.kicad_sch, pritesh.igs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]
2024-12-20 readme: update enclosure info, document leds and switches
    [msx-joypc-v1-case-acrylic-3mm-ready-to-lasercut.dxf]

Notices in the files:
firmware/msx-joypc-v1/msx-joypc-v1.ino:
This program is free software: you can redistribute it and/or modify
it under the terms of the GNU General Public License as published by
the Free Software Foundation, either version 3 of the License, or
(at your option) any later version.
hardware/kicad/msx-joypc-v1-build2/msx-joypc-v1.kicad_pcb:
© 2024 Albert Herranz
